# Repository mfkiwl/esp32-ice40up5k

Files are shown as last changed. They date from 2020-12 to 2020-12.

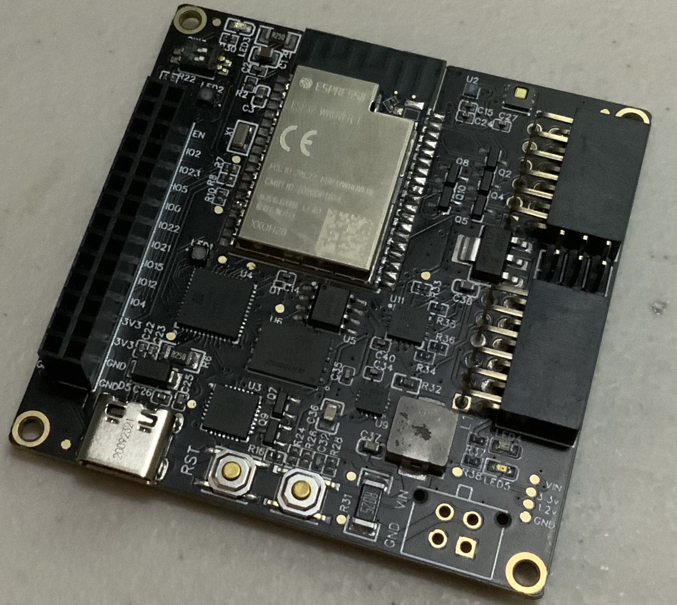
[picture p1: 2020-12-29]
esp32_fpga.jpg

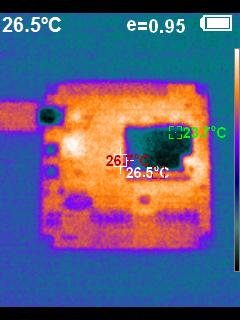
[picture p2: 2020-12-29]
board_files/esp32_ice40_thermal_front.jpg

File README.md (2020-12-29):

# esp32-ice40up5k
Files for a dev board containing an ESP32-Wrover module and an ice40up5k-sg48 FPGA. The ESP32 runs micropython (http://micropython.org/) and uploads the binay image to the FPGA via an spi-like interface. The fpga images are compiled using Project IceStorm: http://www.clifford.at/icestorm/. The FPGA is also attached to external spi flash and ram. The intent of this board is to make fpga prototyping easier by providing simpler interfaces into and out of the FPGA and by allowing the FPGA to "piggyback" off of the ESP32.

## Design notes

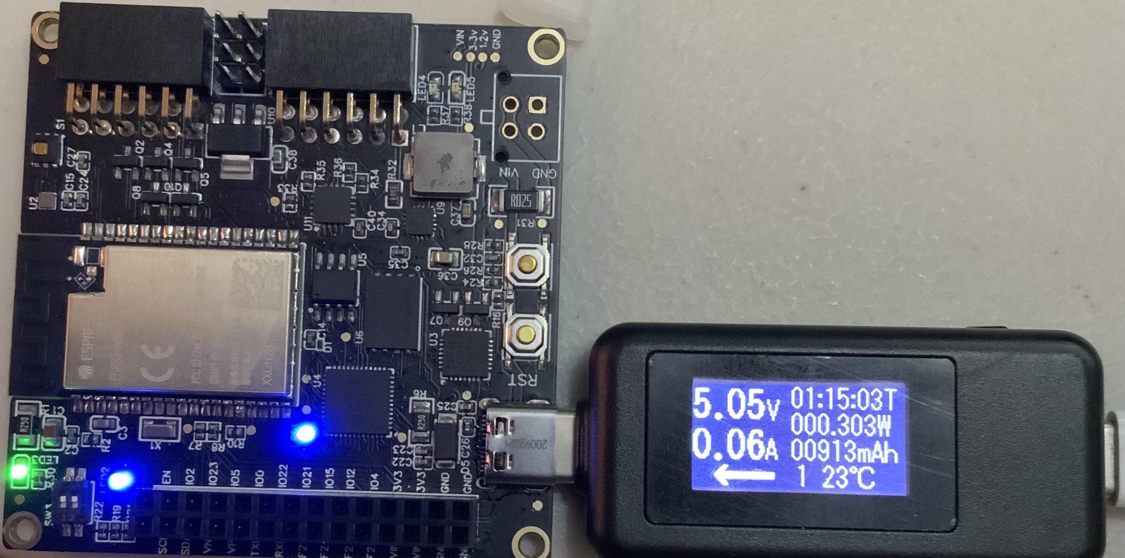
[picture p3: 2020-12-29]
board_files/esp32_ice40_power.jpg

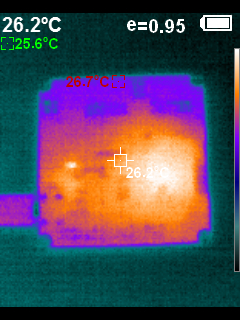
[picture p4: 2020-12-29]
board_files/esp32_ice40_thermal_back.jpg

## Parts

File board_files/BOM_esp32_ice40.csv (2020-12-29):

ID | Name | Designator | Footprint | Quantity | Manufacturer Part | Manufacturer | Supplier | Supplier Part | LCSC Assembly
1 | 1uF | C11,C19,C16,C4,C22,C44,C43 | C0402 | 7 | CL05A105KO5NNNC | SAMSUNG | LCSC | C29266
2 | SDM02M30LP3-7B | D1 | X3-DFN0603-2_L0.6-W0.3-RD | 1 | SDM02M30LP3-7B | Diodes Incorporated | LCSC | C155368
3 | 2K | R15 | R0402 | 1 | 0402WGF2001TCE | UniOhm | LCSC | C4109 | Yes
4 | BMM150 | U2 | WLCSP-12_L1.6-W1.6_BMM150 | 1 | BMM150 | Bosch Sensortec | LCSC | C171681
5 | AMS1117-1.2_C347218 | U10 | SOT-223_L6.7-W3.5-P2.30-BR | 1 | AMS1117-1.2 | Youtai Semiconductor Co., Ltd. | LCSC | C347218
6 | LY68L6400SLIT | U5 | SOP-8_L4.9-W3.9-P1.27-LS6.0-BL | 1 | LY68L6400SLIT | Lyontek Inc. | LCSC | C261881 | Yes
7 | PESDNC2FD5VB | D4,D3,D2 | DFN1006-2L-BI | 3 | PESDNC2FD5VB | Prisemi | LCSC | C110694
8 | ICE40UP5K-SG48 | U4 | VFQFN-48 | 1 | iCE40UP5K-SG48 | Lattice | Digi-Key | 220-2212-1-ND
9 | SS14 | D5 | SMA_L4.4-W2.8-LS5.4-RD | 1 | SS14 | MDD | LCSC | C2480 | Yes
10 | 100K | R32 | R0603 | 1 | 0603WAF1003T5E | UniOhm | LCSC | C25803 | Yes
11 | 22uF | C37 | C0603 | 1 | GRM188B30J226MEA0D | MuRata | LCSC | C15500
12 | 10K | R5,R4,R29,R30,R23,R20,R18,R10,R2,R16,R3,R28,R7,R8,R35,R36,R34,R33,R38,R37 | R0402 | 20 | 0402WGF1002TCE | UniOhm | LCSC | C25744 | Yes
13 | W25Q256JVEIQTR | U6 | WSON-8_L8.0-W6.10-P1.27-TL-EP | 1 | W25Q256JVEIQTR | Winbond Elec | LCSC | C97522 | Yes
14 | 100nF | C35 | C0402 | 1 | TCC0402X7R104K250AT | CCTC | LCSC | C466234
15 | TP_FLT | TP3,TP4,TP5,TP6,TP7,TP1,TP2,TP10,TP12,TP13,TP14,TP15,TP11,TP9,TP8,TP16,TP17,TP18 | TP_FLT | 18
16 | TS-1187A-C-C-B | SW2,SW1 | SW-SMD_4P-L5.1-W5.1-P3.70-LS6.4 | 2 | TS-1187A-C-C-B | XKB Enterprise | LCSC | C318889 | Yes
17 | 10nF | C13,C21,C18,C6,C51,C48 | C0603 | 6 | CC0603KRX7R9BB103 | YAGEO | LCSC | C100042
18 | S8050-G_C164892 | Q1,Q3,Q6 | SOT-23-3_L2.9-W1.3-P1.90-LS2.4-BR | 3 | S8050-G | Changjiang Electronics Tech (CJ) | LCSC | C164892 | Yes
19 | A2541HWR-2X6P | H2,H1 | HDR-TH_12P-P2.54-H-R2-C6-S2.54-W10.2 | 2 | A2541HWR-2x6P | Changjiang Connectors | LCSC | C239357
20 | ORH-G36G | LED3 | LED0603-R-RD | 1 | ORH-G36G | Orient | LCSC | C205443 | Yes
21 | FC-D1608HYK-588J | LED4 | LED0603-RD | 1 | FC-D1608HYK-588J | NATIONSTAR | LCSC | C84268 | Yes
22 | LBSS138LT1G | Q8,Q10,Q5,Q4,Q2,Q9,Q7 | SOT-23_L2.9-W1.3-P0.95-LS2.4-BR | 7 | LBSS138LT1G | LRC | LCSC | C8490 | Yes
23 | 100nF | C2,C26,C27 | C0402 | 3 | CL05B104KB54PNC | Samsung Electro-Mechanics | LCSC | C307331 | Yes
24 | 19-217/R6C-AL1M2VY/3T | LED5 | LED0603-R-RD | 1 | 19-217/R6C-AL1M2VY/3T | EVERLIGHT | LCSC | C72044 | Yes
25 | 1K | R25,R27,R19,R21,R22,R26,R24 | R0402 | 7 | 0402WGF1001TCE | UniOhm | LCSC | C11702 | Yes
26 | PZ254V-12-6P | H3 | HDR-TH_6P-P2.54-V-M-R2-C3-S2.54 | 1 | PZ254V-12-6P | XFCN | LCSC | C492420
27 | 2.2uH | L1 | IND-SMD_L7.4-W6.6 | 1 | TMAX-0630-2R2-M | TDG | LCSC | C429782
28 | 390pF | C34 | C0402 | 1 | CC0402KRX7R9BB391 | YAGEO | LCSC | C114397
29 | DHN-02-V-T/R | SW3 | SW-SMD_4P-L3.8-W4.5-P1.27-LS6.7 | 1 | DHN-02-V-T/R | Diptronics | LCSC | C224995
30 | FM-B2020RGBA-HG | LED1,LED2 | LED-SMD_FM-B2020RGBA-HG | 2 | FM-B2020RGBA-HG | NATIONSTAR | LCSC | C108793 | Yes
31 | 1nF | C33,C32 | C0402 | 2 | 0402B102K500NT | FH | LCSC | C1523 | Yes
32 | 12pF | C8,C7 | C0603 | 2 | 0603CG120J500NT | FH | LCSC | C1642
33 | 22uF | C1 | C0805 | 1 | GRM21BR61E226ME44L | MuRata | LCSC | C86816
34 | 24K | R14 | R0402 | 1 | 0402WGF2402TCE | UniOhm | LCSC | C25769 | Yes
35 | 4.7uF | C25 | C0402 | 1 | JMK105BBJ475MV-F | TAIYO YUDEN | LCSC | C87147
36 | CP2102-GMR | U3 | QFN-28_L5.0-W5.0-P0.50-BL-EP | 1 | CP2102-GMR | SILICON LABS | LCSC | C6568 | Yes
37 | 105450-0101 | USBC1 | USB-C-SMD_TYPE-C-USB-18 | 1 | 105450-0101 | MOLEX | LCSC | C134092
38 | 2.2K | R13 | R0402 | 1 | 0402WGJ0222TCE | UniOhm | LCSC | C25933
39 | ESP32-WROVER-E(16MB) | U1 | WIFIM-SMD_39P-L31.4-W18.0-P1.27 | 1 | ESP32-WROVER-E(16MB) | Espressif Systems | LCSC | C529589
40 | INA3221AIRGVR | U11 | QFN-16_L4.0-W4.0-P0.65-TL-EP2.2 | 1 | INA3221AIRGVR | Texas Instruments | LCSC | C181255 | Yes
41 | 0.25 | R6,R1 | R1206 | 2 | 1206W4F250LT5E | UniOhm | LCSC | C49283 | Yes
42 | 100 | R12 | R0603 | 1 | RTT03101JTP | RALEC | LCSC | C103204 | Yes
43 | HDC1080DMBR | S1 | SENSOR-SMD_HDC1080DMBR | 1 | HDC1080DMBR | TI | LCSC | C82227
44 | Header-Female-2.54_2x14 | P1 | HDR-TH_28P-P2.54-V-R2-C14-S2.54 | 1 | 2×14 Double female header | BOOMELE | LCSC | C60375
45 | 100nF | C14,C9,C12,C20,C17,C5,C31,C30,C29,C28,C23,C15,C24,C50,C49,C47,C46,C45,C40 | C0402 | 19 | CL05B104KO5NNNC | SAMSUNG | LCSC | C1525 | Yes
46 | 10uF | C10,C3,C38,C39,C42,C41 | C0603 | 6 | CC0603KRX5R6BB106 | YAGEO | LCSC | C326057
47 | 32.768KHz | X1 | OSC-SMD_L3.2-W1.5 | 1 | AH03270014 | TXC Corp | LCSC | C409356
48 | 430450412 | U8 | CONN-TH_4P-P3.00-S3.00_L7.4-W9.7-EH9.0 | 1 | 430450412 | MOLEX | LCSC | C277721
49 | 0.025 | R31 | R2010 | 1 | RL2010FK-070R025L | YAGEO | LCSC | C309642
50 | 47K | R17 | R0402 | 1 | 0402WGF4702TCE | UniOhm | LCSC | C25792 | Yes
51 | 5.1K | R11,R9 | R0603 | 2 | 0603WAF5101T5E | UniOhm | LCSC | C23186 | Yes
52 | TPS62132RGTR | U9 | VQFN-16_L3.0-W3.0-P0.50-BL-EP | 1 | TPS62132RGTR | Texas Instruments | LCSC | C81563 | Yes
53 | 10uF | C36 | C0805 | 1 | 0805X106K250NT | FH | LCSC | C40894

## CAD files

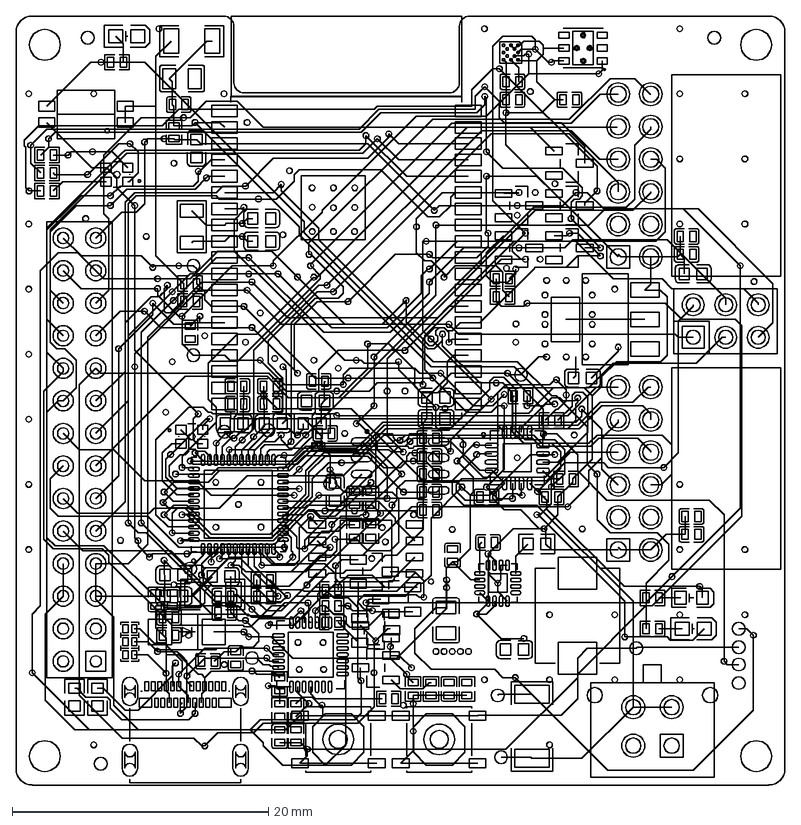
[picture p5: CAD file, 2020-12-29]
board_files/PCB_esp32_ice40.dxf
60.0 x 60.0 mm

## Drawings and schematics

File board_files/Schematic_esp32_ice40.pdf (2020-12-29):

# A1 A1 A2 A2 A3 A3 A4 A4 A5 A5 A6 A6 A7 A7 A8 A8 A9 A9 A10 A10 A11 A11 A12 A12

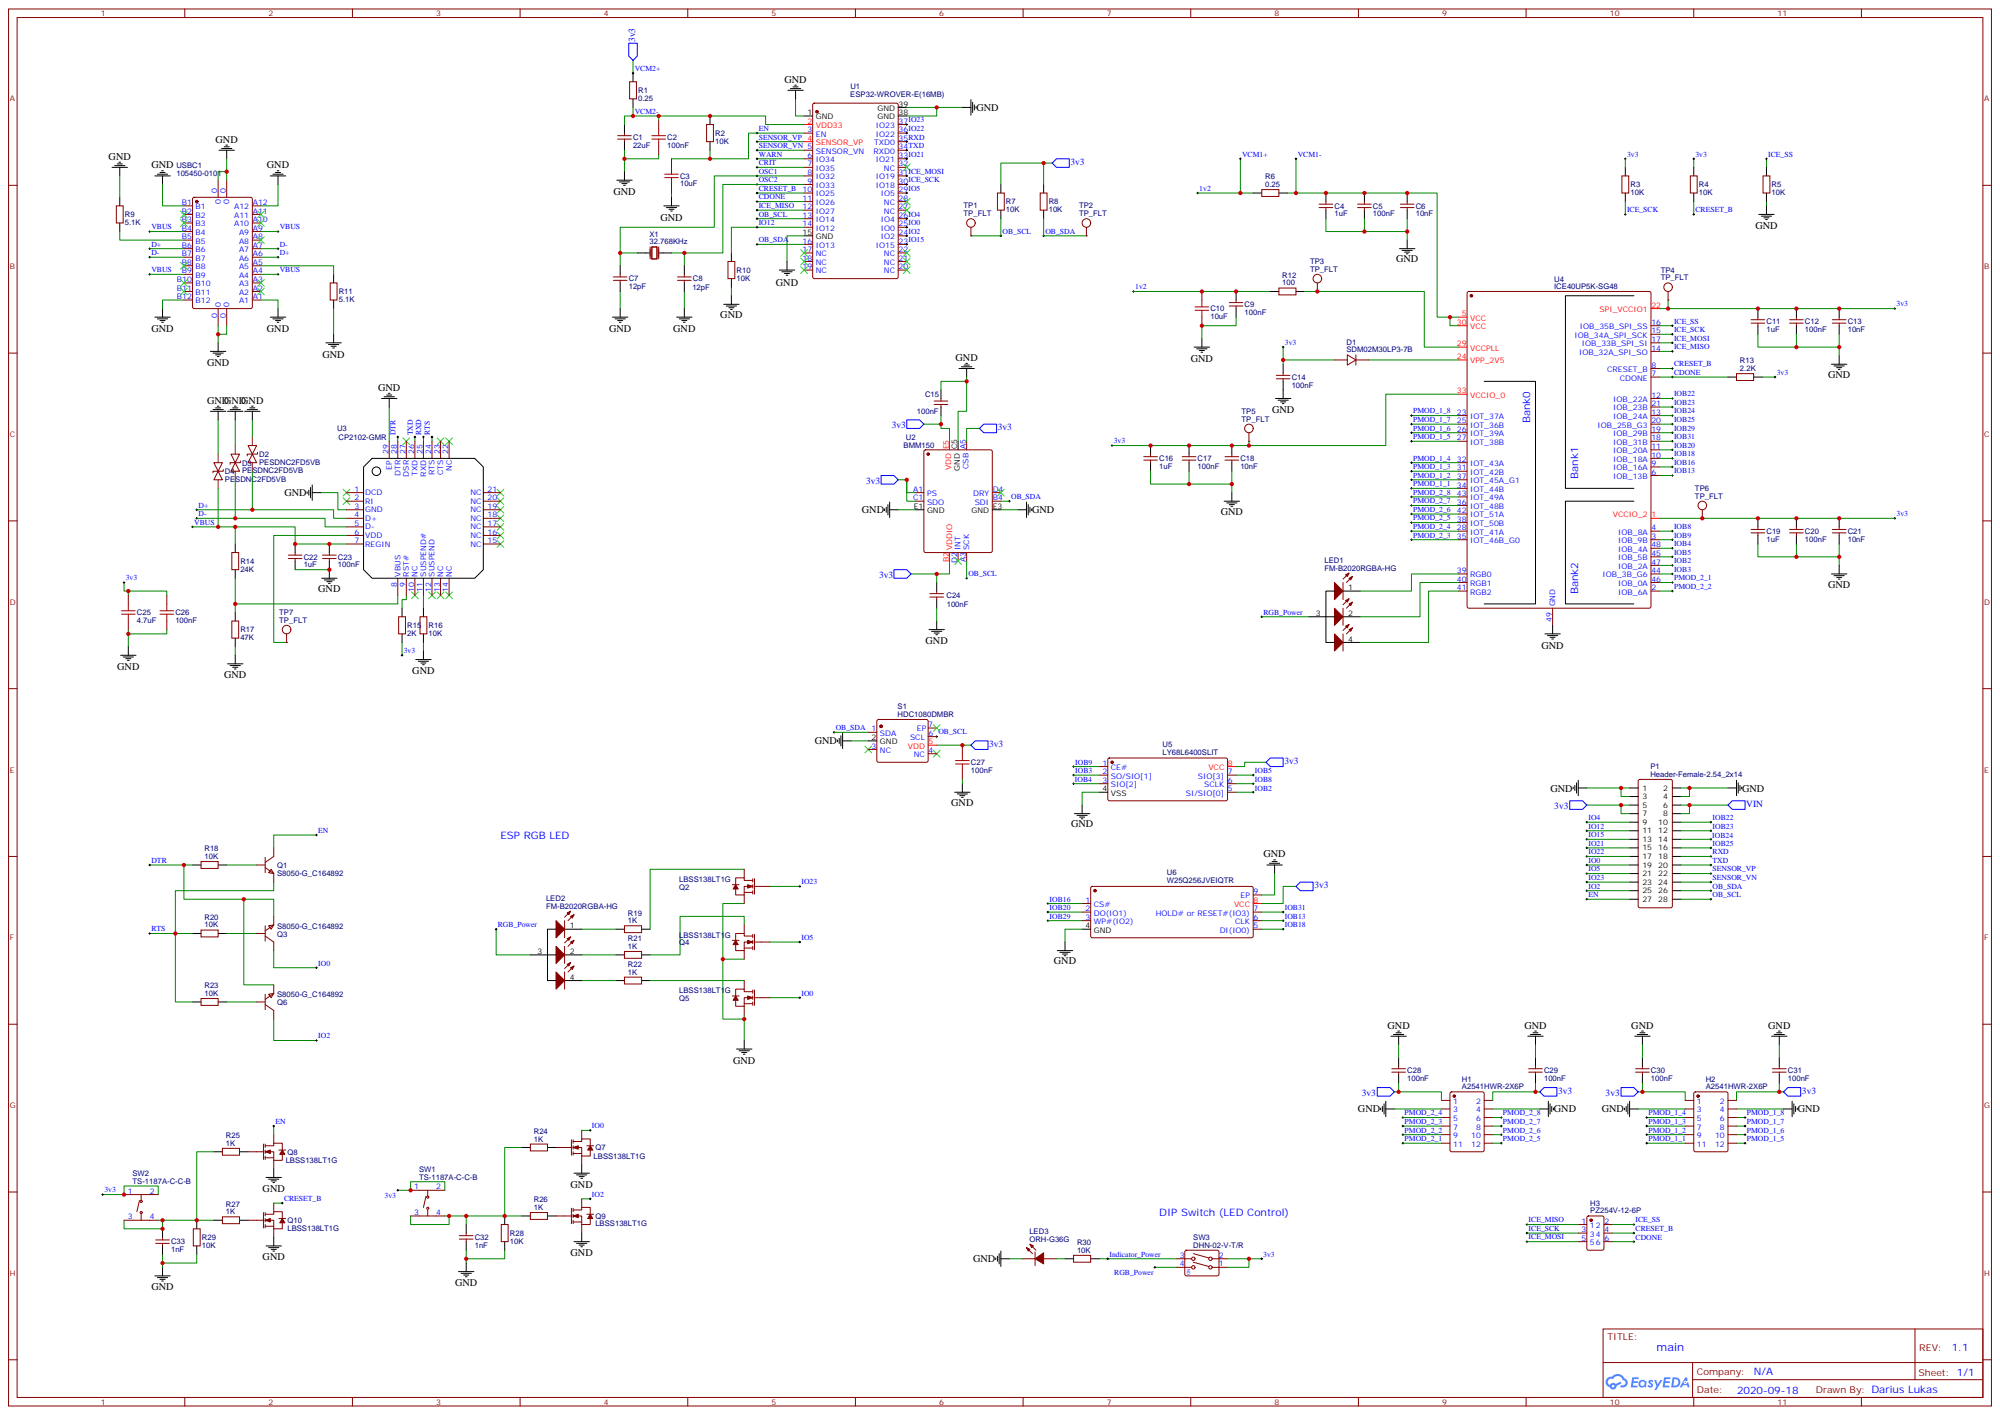
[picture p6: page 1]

NC 22 CTS 23 RTS 24 RXD 25 TXD 26 DSR 27 DTR 28 EP 29

DIP Switch (LED Control)

Drawn By: Darius Lukas

# GNDFSW FSW

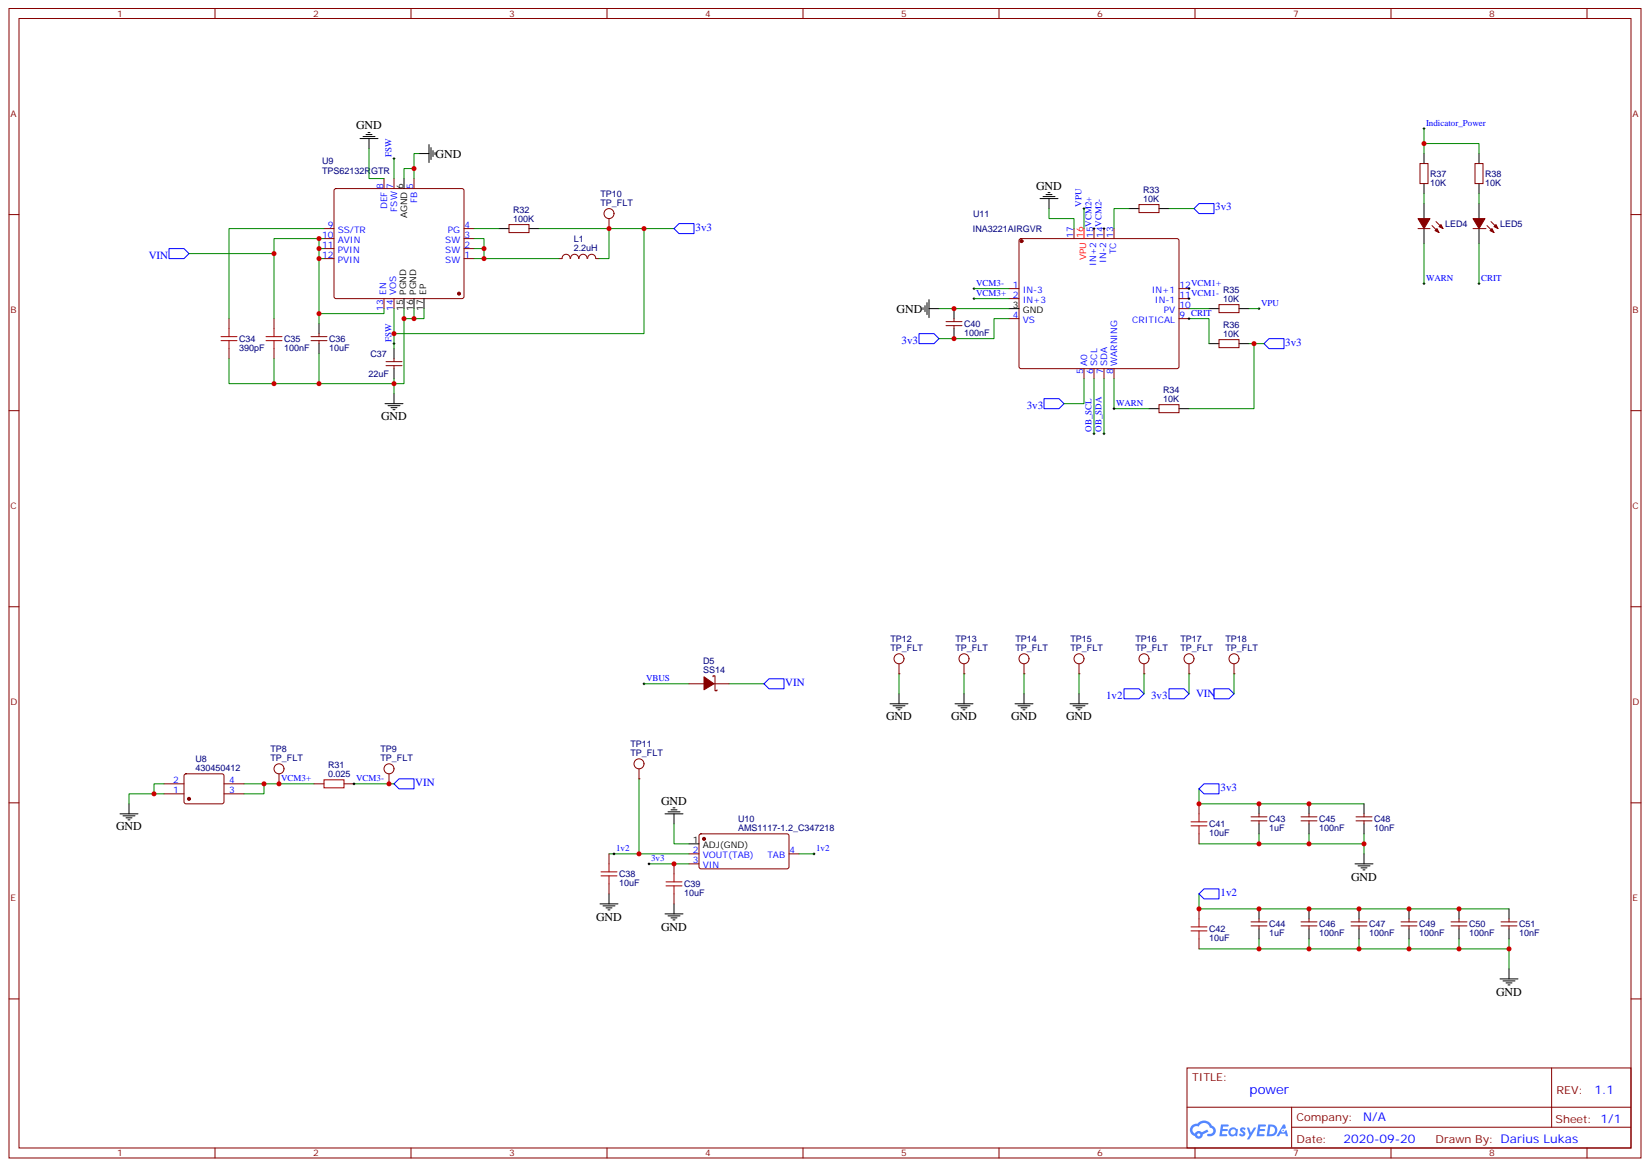
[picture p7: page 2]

Drawn By: Darius Lukas

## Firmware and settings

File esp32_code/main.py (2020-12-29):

def do_connect():
    import network
    wlan = network.WLAN(network.STA_IF)
    wlan.active(True)
    if not wlan.isconnected():
        print('connecting to network...')
        wlan.connect('INSERT WIFI NAME HERE', 'INSERT PASSWORD HERE')
        while not wlan.isconnected():
            pass
    print('network config:', wlan.ifconfig())

from machine import Pin
red = Pin(23, Pin.OUT)
blue = Pin(5, Pin.OUT)
green = Pin(0, Pin.OUT)

red.on()
blue.off()
green.off()

import machine
machine.freq(240000000)

do_connect()

# Program FPGA
import fpga
fpga.upload('blink.bin')


red.off()
blue.on()

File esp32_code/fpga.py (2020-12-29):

import machine
from machine import SPI, Pin
import time


def upload(filename):
    # Read in the binary fpga configuration
    fpga_file = open(filename, 'rb')
    bblob = fpga_file.read()
    fpga_file.close()

    # Setup a soft SPI bus (18, 27, 19)
    spi = machine.SPI(baudrate=4000000, polarity=1, phase=0, sck=Pin(18), mosi=Pin(19), miso=Pin(27))

    spi.init(baudrate=4000000)

    ICE_SS = Pin(14, Pin.OUT) # 14
    CRESET_B = Pin(25, Pin.OUT) # 25
    CDONE = Pin(26, Pin.IN) # 26

    ICE_SS.value(0)
    CRESET_B.value(0)   # Reset the FPGA
    time.sleep_ms(1)
    CRESET_B.value(1)
    time.sleep_ms(1)

    spi.write(bblob)

    for x in range(8):
        spi.write(b'0')

    print(CDONE.value())
